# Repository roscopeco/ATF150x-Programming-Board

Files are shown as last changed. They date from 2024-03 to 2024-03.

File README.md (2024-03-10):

## JTAG Programming & Testing Board for ATF1502 & 1504 CPLDs

### What

This is a small board to support JTAG programming (tested with Microchip ATDH1150USB) 
and general testing of ATF15xx CPLDs.

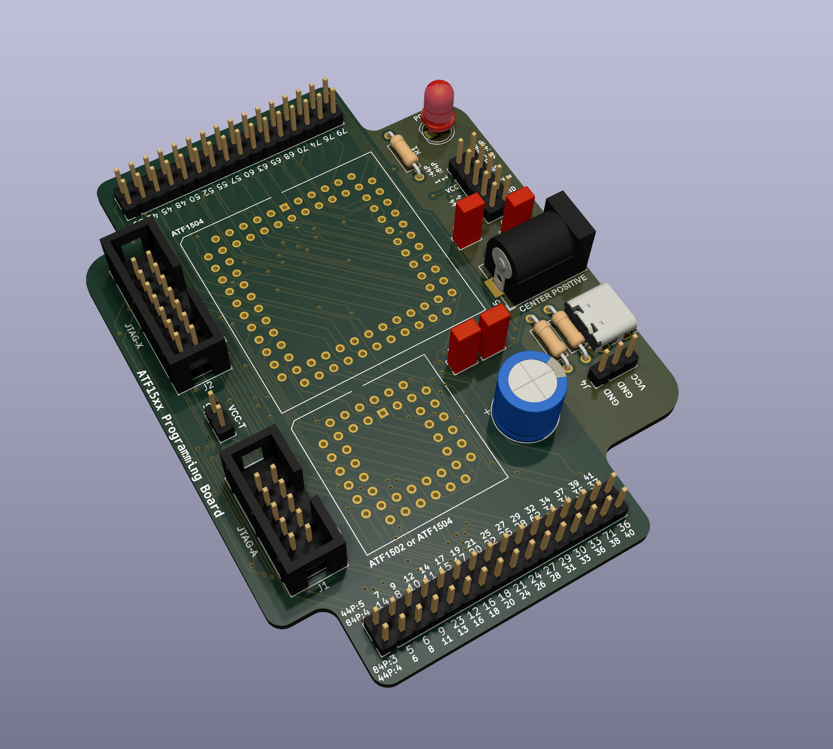
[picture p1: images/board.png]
Board image


PLCC44 and PLCC84 variants are directly supported. Power can come from DuPonts, a
5V barrel jack or USB-C.

Board is four layer, and should be easily manufacturable by pretty much any fab you
care to use (I like JLCPCB, YMMV). It's quite small so should be reasonably cheap,
and all components are through-hole so nice and easy to solder.

The are really the last good 5V CPLDs that are in production - make use of them,
encourage Microchip to not discontinue them!

* [ATF1502](https://www.microchip.com/en-us/product/atf1502as)
* [ATF1504](https://www.microchip.com/en-us/product/atf1504as)

### Why?

I needed a board to do some testing with ATF1504 CPLDs for a new 
[rosco_m68k](https://github.com/rosco-m68k/rosco_m68k) thing I was
working on, and thought it might also be useful to others. So here you go.

### Who

Copyright (c)2024 Ross Bamford
Licensed under the Strongly Reciprocal CERN-OHL-S license. 
See LICENSE.md for details

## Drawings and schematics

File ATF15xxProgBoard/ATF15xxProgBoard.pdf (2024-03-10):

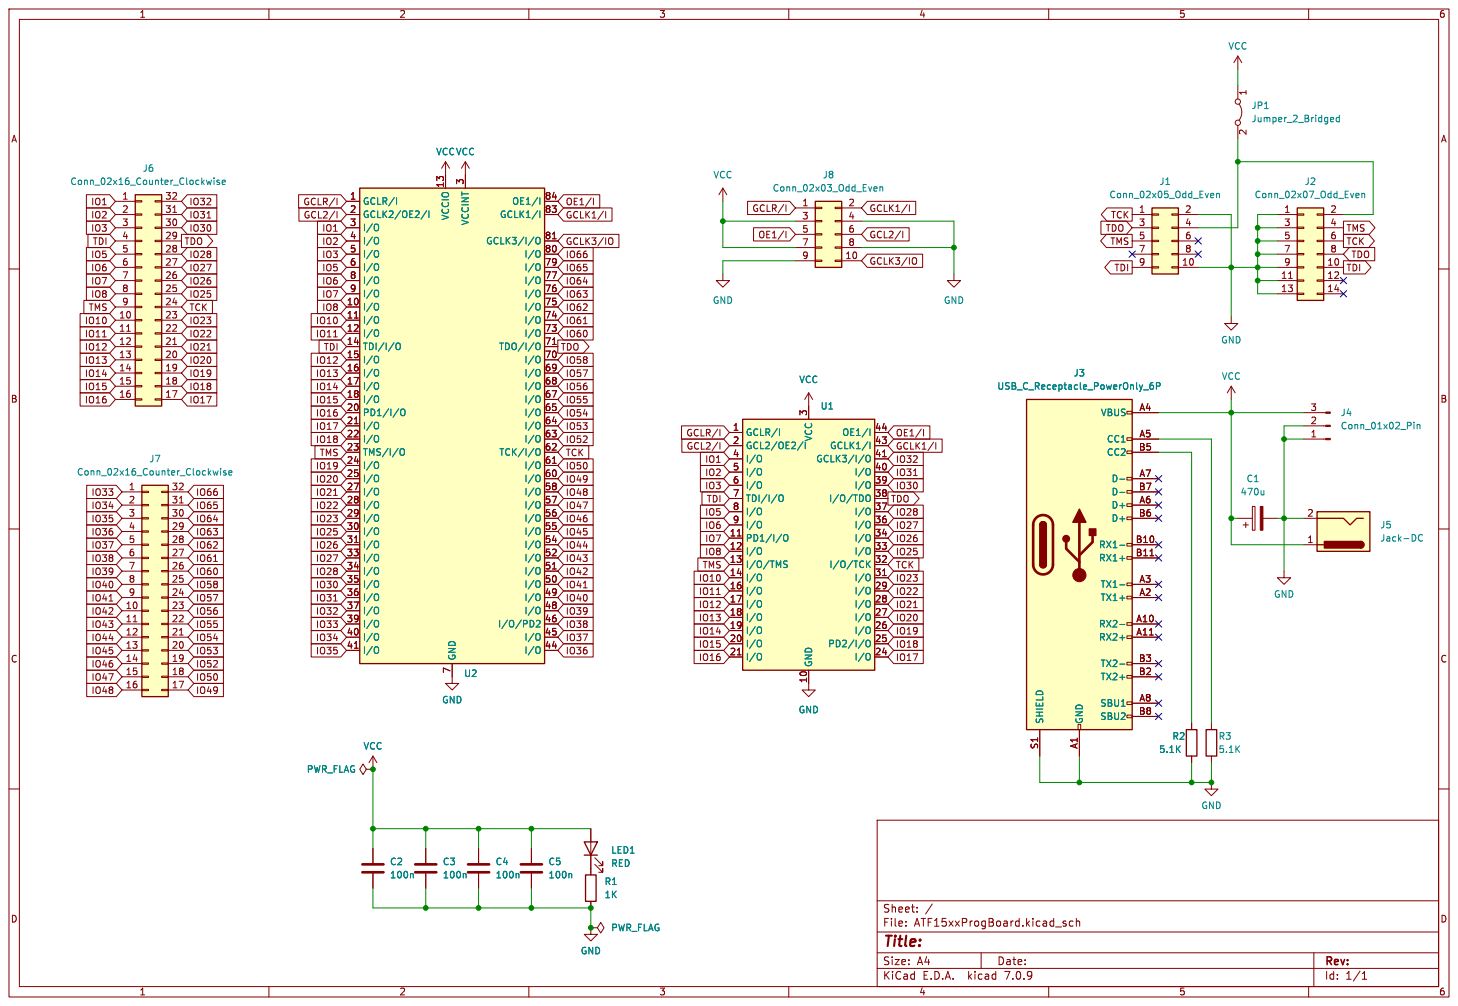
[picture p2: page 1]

Id: 1/1 Title: File: ATF15xxProgBoard.kicad_sch Sheet: /

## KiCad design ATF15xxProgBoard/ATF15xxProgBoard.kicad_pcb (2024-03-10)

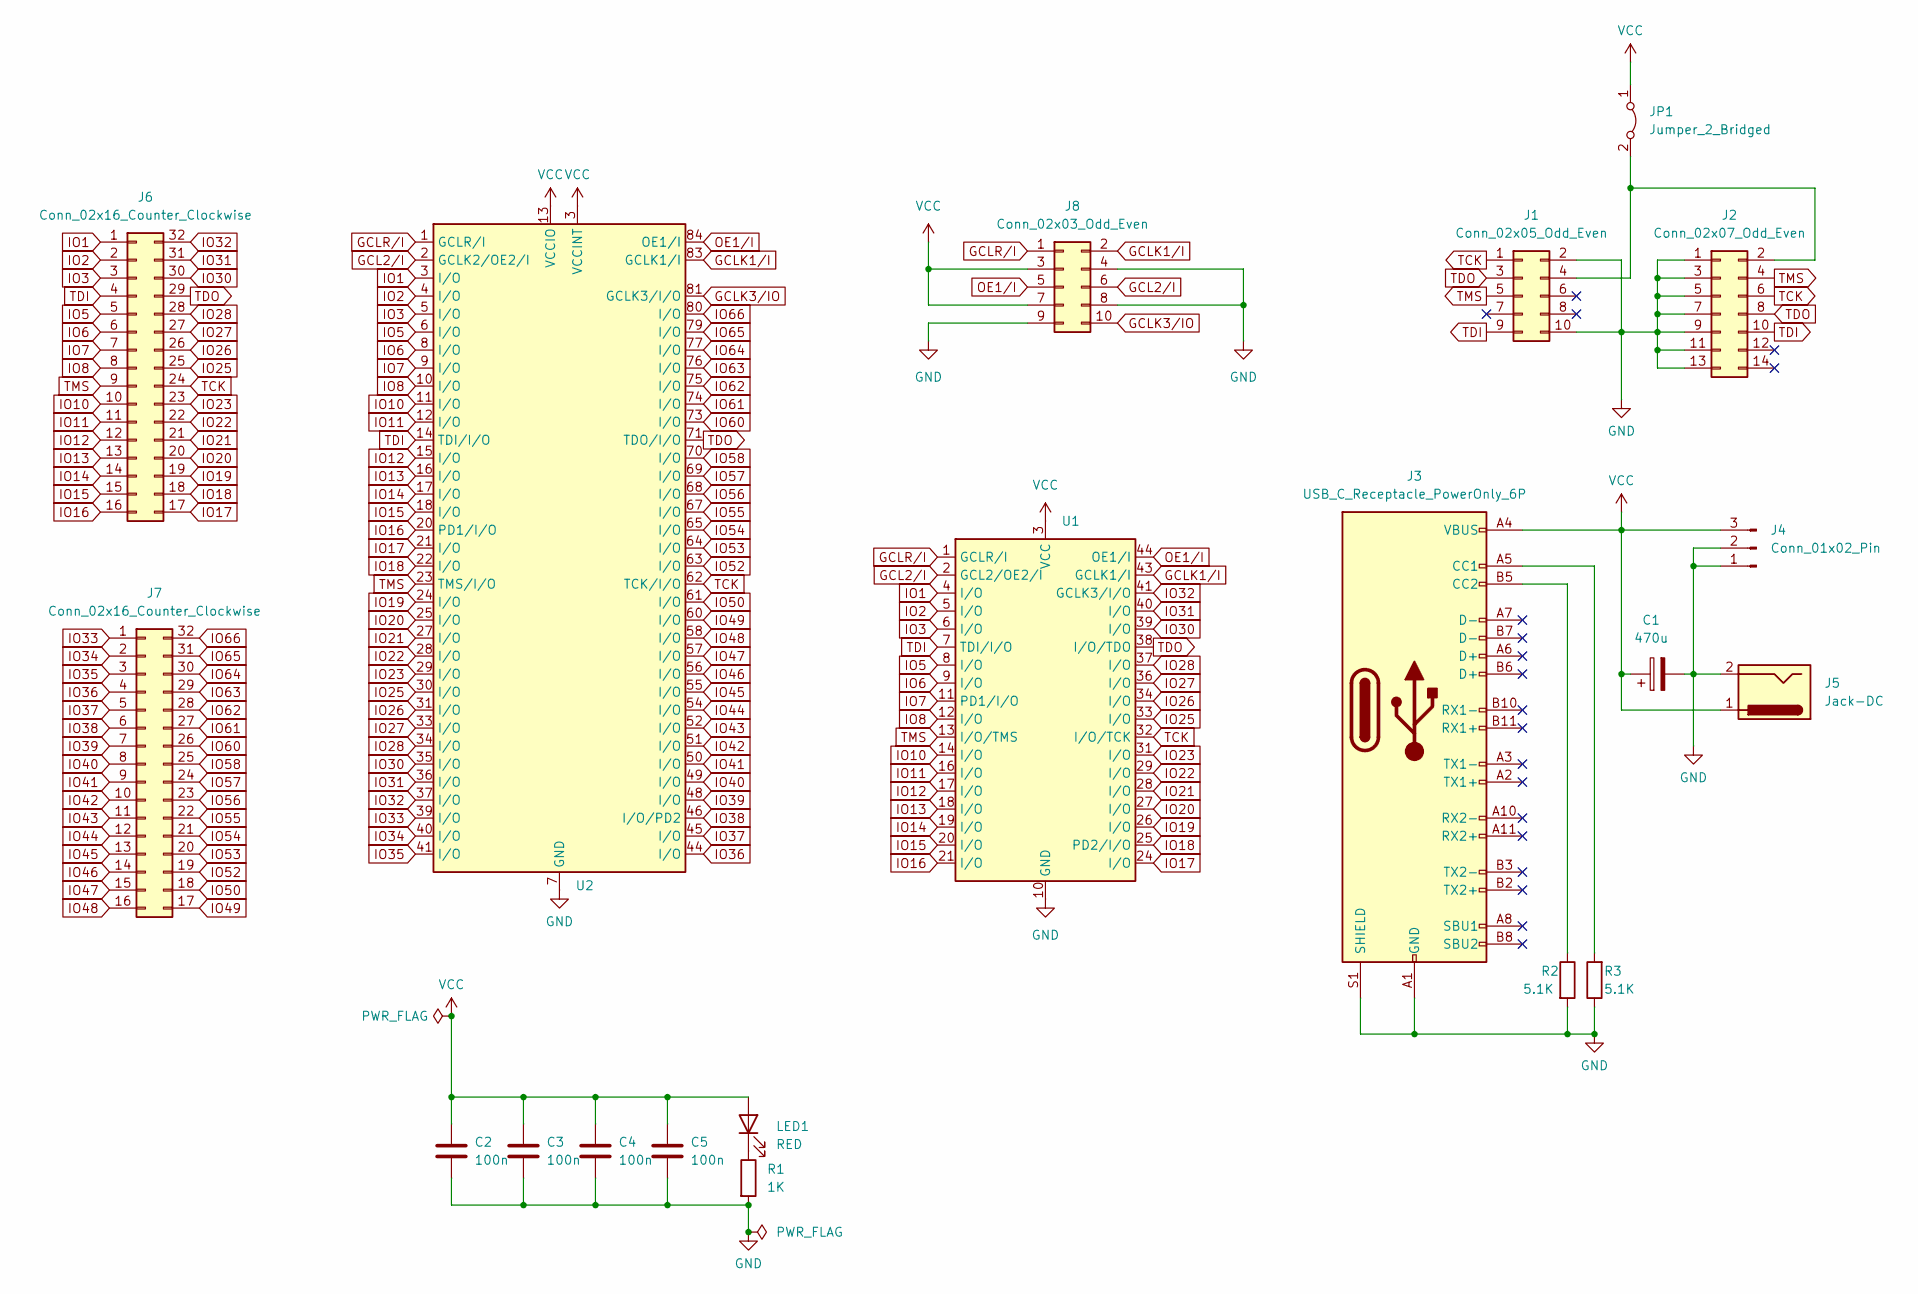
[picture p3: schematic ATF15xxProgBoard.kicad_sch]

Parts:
C1: 470u; CP_Radial_D10.0mm_P3.80mm
C2, C3, C4, C5: 100n; C_Rect_L4.0mm_W2.5mm_P2.50mm
J1: Conn_02x05_Odd_Even; IDC-Header_2x05_P2.54mm_Vertical
J2: Conn_02x07_Odd_Even; IDC-Header_2x07_P2.54mm_Vertical
J3: USB_C_Receptacle_PowerOnly_6P; USB_C_Receptacle_Palconn_UTC16-G
J4: Conn_01x02_Pin; PinHeader_1x03_P2.54mm_Vertical
J5: Jack-DC; BarrelJack_Horizontal
J6, J7: Conn_02x16_Counter_Clockwise; PinHeader_2x16_P2.54mm_Vertical
J8: Conn_02x03_Odd_Even; PinHeader_2x05_P2.54mm_Vertical
JP1: Jumper_2_Bridged; PinHeader_1x02_P2.54mm_Vertical
LED1: RED; LED_D5.0mm
R1: 1K; R_Axial_DIN0207_L6.3mm_D2.5mm_P10.16mm_Horizontal
R2, R3: 5.1K; R_Axial_DIN0207_L6.3mm_D2.5mm_P10.16mm_Horizontal
U1: PLCC-44_THT-Socket
U2: PLCC-84_THT-Socket

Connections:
GCL2/I: J8.6, U1.2 (GCL2/OE2/I), U2.2 (GCLK2/OE2/I)
GCLK1/I: J8.2, U1.43 (GCLK1/I), U2.83 (GCLK1/I)
GCLK3/IO: J8.10, U2.81 (GCLK3/I/O)
GCLR/I: J8.1, U1.1 (GCLR/I), U2.1 (GCLR/I)
GND: C1.2, C2.2, C3.1, C4.2, C5.2, J1.2, J1.10, J2.1, J2.3, J2.5, J2.7, J2.9, J2.11, J2.13, J3.A1 (GND), J3.A12 (GND), J3.B1 (GND), J3.B12 (GND), J3.S1 (SHIELD), J4.1, J4.2, J5.2, J8.4, J8.8, J8.9, R1.2, R2.2, R3.1, U1.10 (GND), U1.22 (GND), U1.30 (GND), U1.42 (GND), U2.7 (GND), U2.19 (GND), U2.32 (GND), U2.42 (GND), U2.47 (GND), U2.59 (GND), U2.72 (GND), U2.82 (GND)
IO2: J6.2, U1.5 (I/O), U2.4 (I/O)
IO3: J6.3, U1.6 (I/O), U2.5 (I/O)
IO5: J6.5, U1.8 (I/O), U2.6 (I/O)
IO6: J6.6, U1.9 (I/O), U2.8 (I/O)
IO7: J6.7, U1.11 (PD1/I/O), U2.9 (I/O)
IO8: J6.8, U1.12 (I/O), U2.10 (I/O)
IO10: J6.10, U1.14 (I/O), U2.11 (I/O)
IO11: J6.11, U1.16 (I/O), U2.12 (I/O)
IO12: J6.12, U1.17 (I/O), U2.15 (I/O)
IO13: J6.13, U1.18 (I/O), U2.16 (I/O)
IO14: J6.14, U1.19 (I/O), U2.17 (I/O)
IO15: J6.15, U1.20 (I/O), U2.18 (I/O)
IO16: J6.16, U1.21 (I/O), U2.20 (PD1/I/O)
IO17: J6.17, U1.24 (I/O), U2.21 (I/O)
IO18: J6.18, U1.25 (PD2/I/O), U2.22 (I/O)
IO19: J6.19, U1.26 (I/O), U2.24 (I/O)
IO20: J6.20, U1.27 (I/O), U2.25 (I/O)
IO21: J6.21, U1.28 (I/O), U2.27 (I/O)
IO22: J6.22, U1.29 (I/O), U2.28 (I/O)
IO23: J6.23, U1.31 (I/O), U2.29 (I/O)
IO25: J6.25, U1.33 (I/O), U2.30 (I/O)
IO26: J6.26, U1.34 (I/O), U2.31 (I/O)
IO27: J6.27, U1.36 (I/O), U2.33 (I/O)
IO28: J6.28, U1.37 (I/O), U2.34 (I/O)
IO30: J6.30, U1.39 (I/O), U2.35 (I/O)
IO31: J6.31, U1.40 (I/O), U2.36 (I/O)
IO32: J6.32, U1.41 (GCLK3/I/O), U2.37 (I/O)
IO33: J7.1, U2.39 (I/O)
IO34: J7.2, U2.40 (I/O)
IO35: J7.3, U2.41 (I/O)
IO36: J7.4, U2.44 (I/O)
IO37: J7.5, U2.45 (I/O)
IO38: J7.6, U2.46 (I/O/PD2)
IO39: J7.7, U2.48 (I/O)
IO40: J7.8, U2.49 (I/O)
IO41: J7.9, U2.50 (I/O)
IO42: J7.10, U2.51 (I/O)
IO43: J7.11, U2.52 (I/O)
IO44: J7.12, U2.54 (I/O)
IO45: J7.13, U2.55 (I/O)
IO46: J7.14, U2.56 (I/O)
IO47: J7.15, U2.57 (I/O)
IO48: J7.16, U2.58 (I/O)
IO49: J7.17, U2.60 (I/O)
IO50: J7.18, U2.61 (I/O)
IO52: J7.19, U2.63 (I/O)
IO53: J7.20, U2.64 (I/O)
IO54: J7.21, U2.65 (I/O)
IO55: J7.22, U2.67 (I/O)
IO56: J7.23, U2.68 (I/O)
IO57: J7.24, U2.69 (I/O)
IO58: J7.25, U2.70 (I/O)
IO60: J7.26, U2.73 (I/O)
IO61: J7.27, U2.74 (I/O)
IO62: J7.28, U2.75 (I/O)
IO63: J7.29, U2.76 (I/O)
IO64: J7.30, U2.77 (I/O)
IO65: J7.31, U2.79 (I/O)
IO66: J7.32, U2.80 (I/O)
unnamed: J1.4, J2.2, JP1.2 (B)
unnamed: J3.A5 (CC1), R3.2
unnamed: J3.B5 (CC2), R2.1
unnamed: LED1.1 (K), R1.1
OE1/I: J8.5, U1.44 (OE1/I), U2.84 (OE1/I)
TCK: J1.1, J2.6, J6.24, U1.32 (I/O/TCK), U2.62 (TCK/I/O)
TDI: J1.9, J2.10, J6.4, U1.7 (TDI/I/O), U2.14 (TDI/I/O)
TDO: J1.3, J2.8, J6.29, U1.38 (I/O/TDO), U2.71 (TDO/I/O)
TMS: J1.5, J2.4, J6.9, U1.13 (I/O/TMS), U2.23 (TMS/I/O)

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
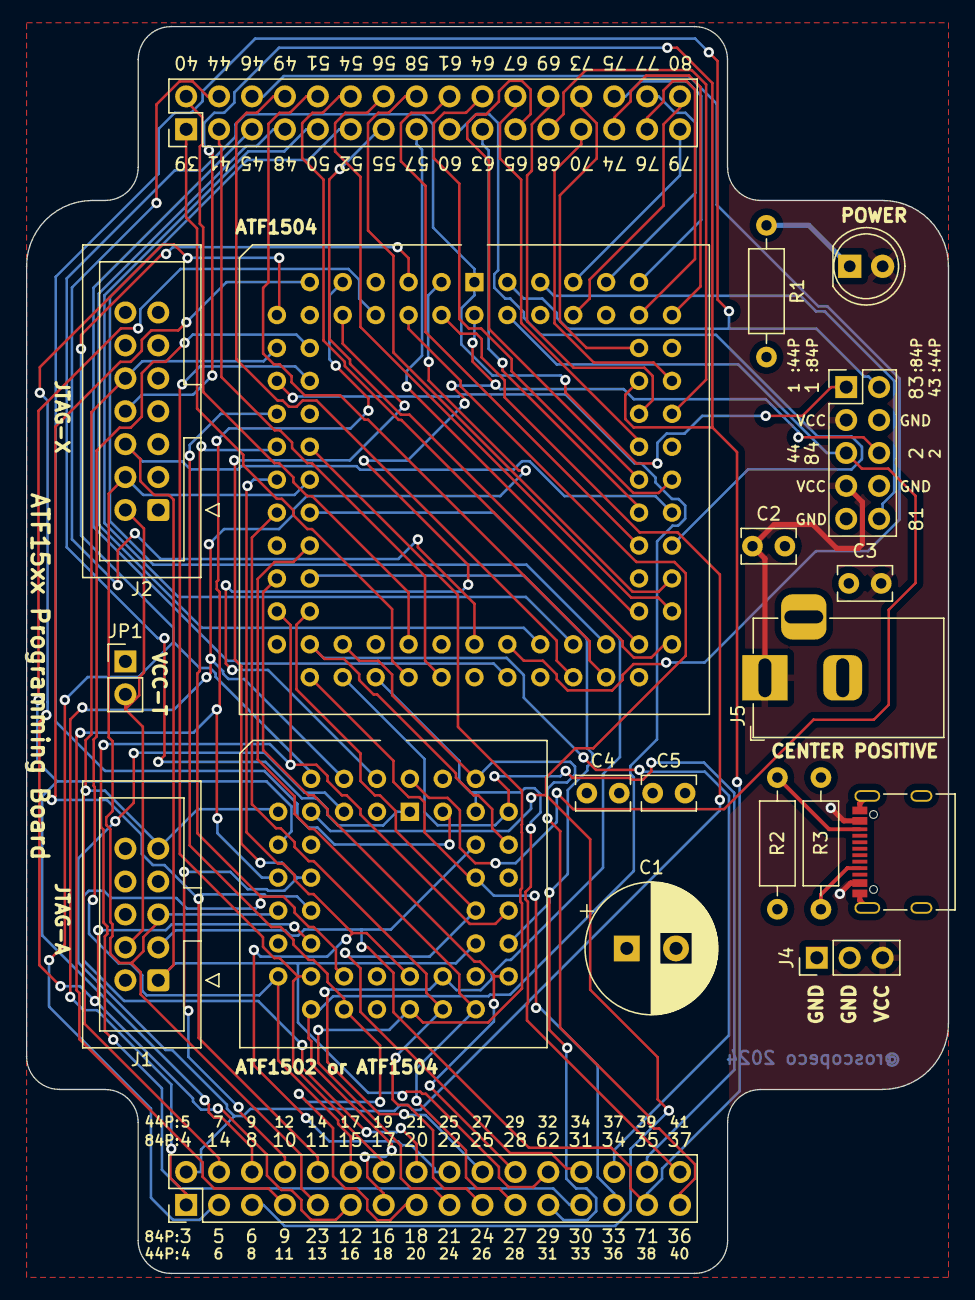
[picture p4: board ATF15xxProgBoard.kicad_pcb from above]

Board: 4 copper layers, 71.1 x 96.2 mm, 20 parts (0 on the bottom side), 75 nets.
